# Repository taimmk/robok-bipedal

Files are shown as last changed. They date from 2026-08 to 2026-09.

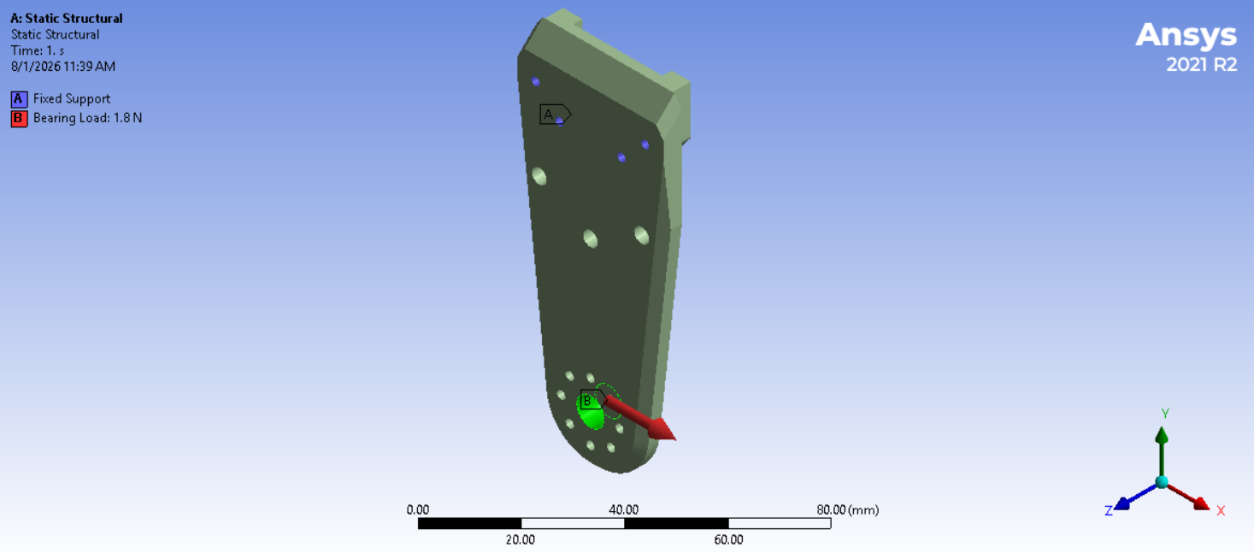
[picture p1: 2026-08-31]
docs/images/ANSYS/linki_setup.png

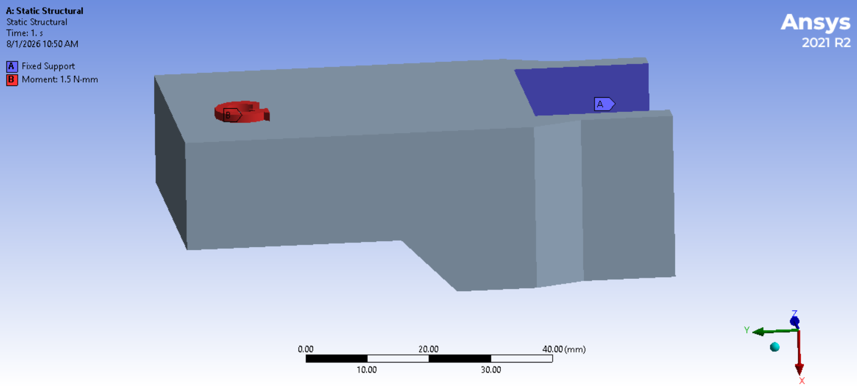
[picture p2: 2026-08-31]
docs/images/ANSYS/hiproll_setup.png

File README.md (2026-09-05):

# robok-bipedal

in this repo you will find all the resources I used to train the Robok (a custom bipedal designed by Taim MKAREM)
you will find all the info regarding installing the Isaac SIM 6.0.1 and training the robot from scratch in the docs/bipedal pdf file. 

for further information feel free to contact me on
taimmkarem@outlook.com

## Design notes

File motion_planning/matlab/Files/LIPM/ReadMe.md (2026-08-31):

# Motion Planning: LIPM Trajectory & Inverse Kinematics Pipeline

This directory contains the MATLAB workflow for generating balanced bipedal walking trajectories using the Linear Inverted Pendulum Model (LIPM), solving joint kinematics, and exporting trajectory matrices for Simulink.

---

## Workflow Overview

```text
[ applicationLIPM.mlapp ] ──> Tune & verify balance parameters
          │
          ▼
[ animateLIPM.m ] ──> Plot leg/COM trajectories ──> Generates: defaultfootinfos.mat
          │
          ▼
[ InverseKinematics_local.m ] ──> Calculate joint positions ──> Generates: IK trajectory data
          │
          ▼
[ Test_gen_mat.m ] ──> Format joint time-series ──> Generates: jointAngs_simulink_ready.mat
          │
          ▼
[ Simulink Model ] ──> Low-level robot execution
```

---

## Prerequisites

- **MATLAB** (R2023a or newer recommended)
- **Toolboxes:** Simulink, Simscape Multibody, Optimization Toolbox

---

## Step-by-Step Execution Guide

### 1. Balance Parameter Configuration

Launch the App Designer interface to configure and verify LIPM balance parameters:

```matlab
applicationLIPM
```

**Objective:** Adjust pendulum height ($z_0$), step time ($T_s$), and step length parameters to ensure zero-moment point (ZMP) stability for the physical robot specifications.

### 2. Trajectory Generation & Visualization

Apply the verified parameters to `animateLIPM.m` to generate and preview leg and Center of Mass (COM) trajectories:

```matlab
run('animateLIPM.m')
```

- **Output:** Displays animated robot walking gait and foot trajectory plots.
- **Generated Artifact:** `defaultfootinfos.mat` — stores target foot placements and time vectors.

### 3. Inverse Kinematics Computation

Compute the exact joint angles required to track the generated foot placements:

```matlab
run('InverseKinematics_local.m')
```

- **Input:** Automatically loads `defaultfootinfos.mat`.
- **Output:** Calculates leg joint positions across the stride cycle using the local-coordinate-frame IK solver.

### 4. Format Trajectories for Simulation

Convert raw joint trajectories into a time-series format optimized for Simulink import:

```matlab
run('Test_gen_mat.m')
```

- **Generated Artifact:** `jointAngs_simulink_ready.mat`

### 5. Load into Simulink

Move `jointAngs_simulink_ready.mat` to your main simulation workspace or load it before launching the Simulink environment:

```matlab
load('jointAngs_simulink_ready.mat');
```

---

## Data Artifacts Summary

| File Name | Producer Script | Description |
| --- | --- | --- |
| `defaultfootinfos.mat` | `animateLIPM.m` | Foot placement coordinates, step timing, and COM trajectories |
| `jointAngs_simulink_ready.mat` | `Test_gen_mat.m` | Time-series joint angle matrix formatted for Simulink block inputs |

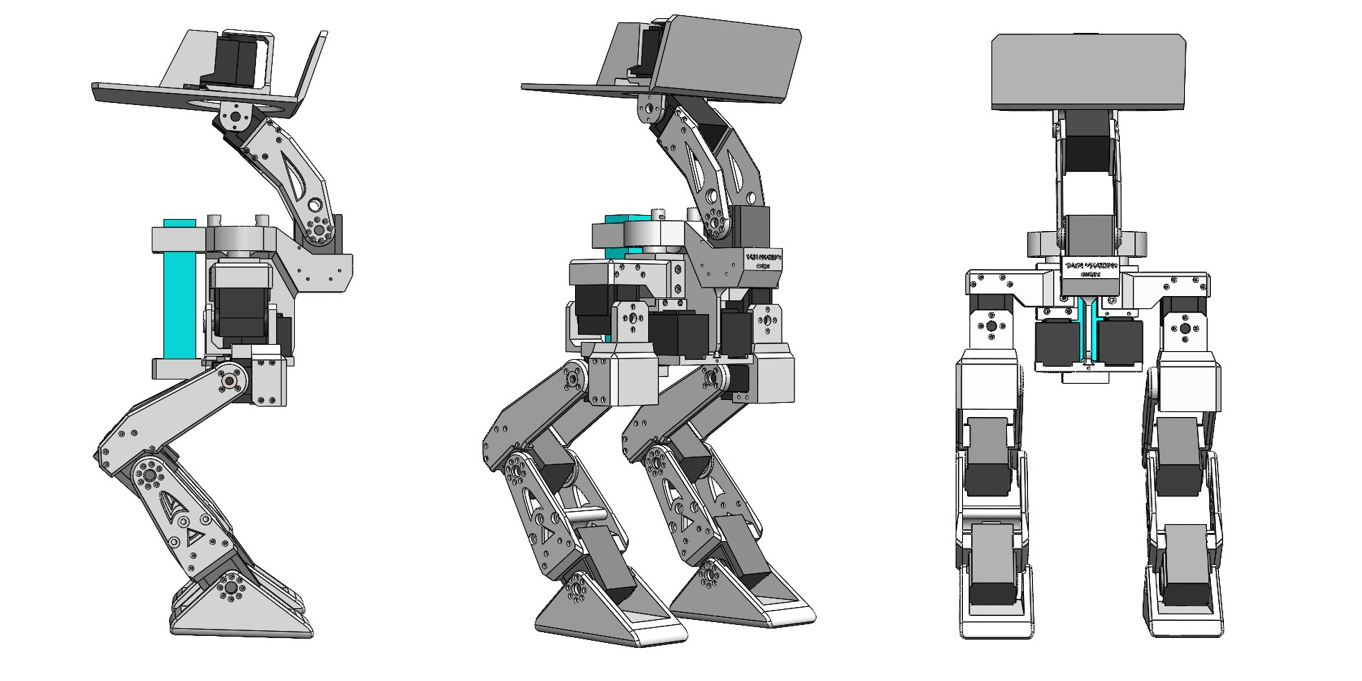
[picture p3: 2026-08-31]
docs/images/design1.png

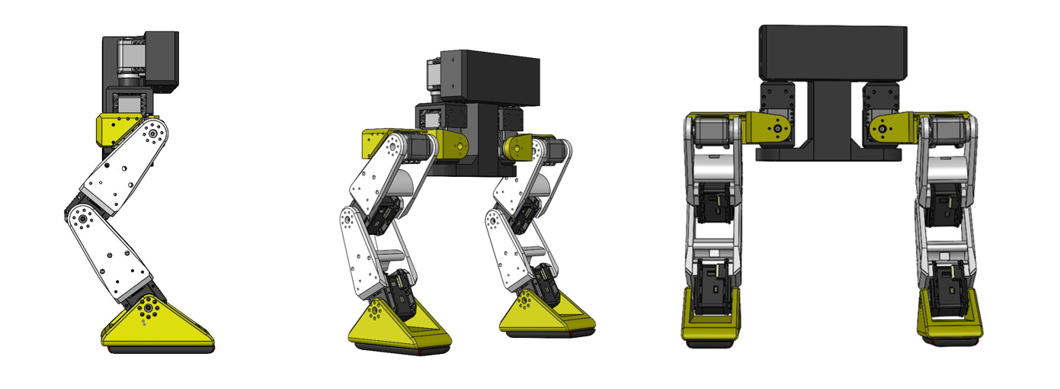
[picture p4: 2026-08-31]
docs/images/design0.png

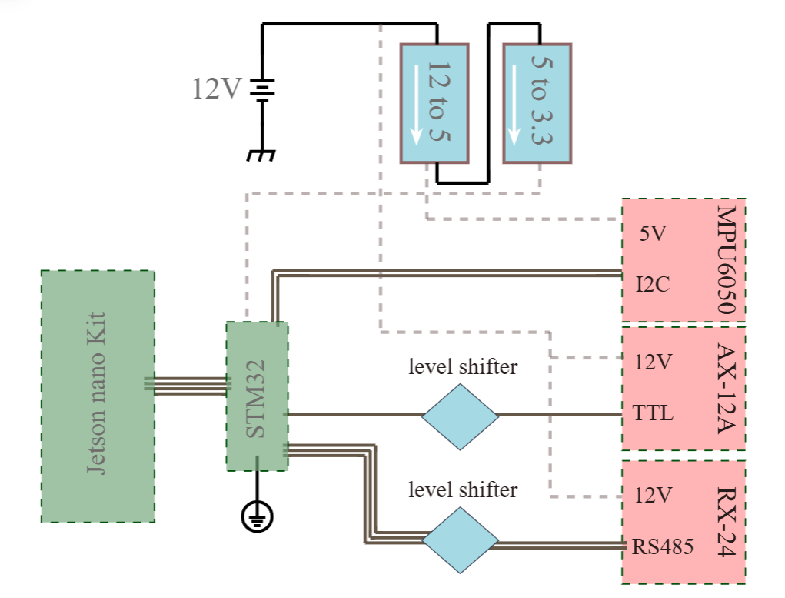
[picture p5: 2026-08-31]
docs/images/pcbdesign.png

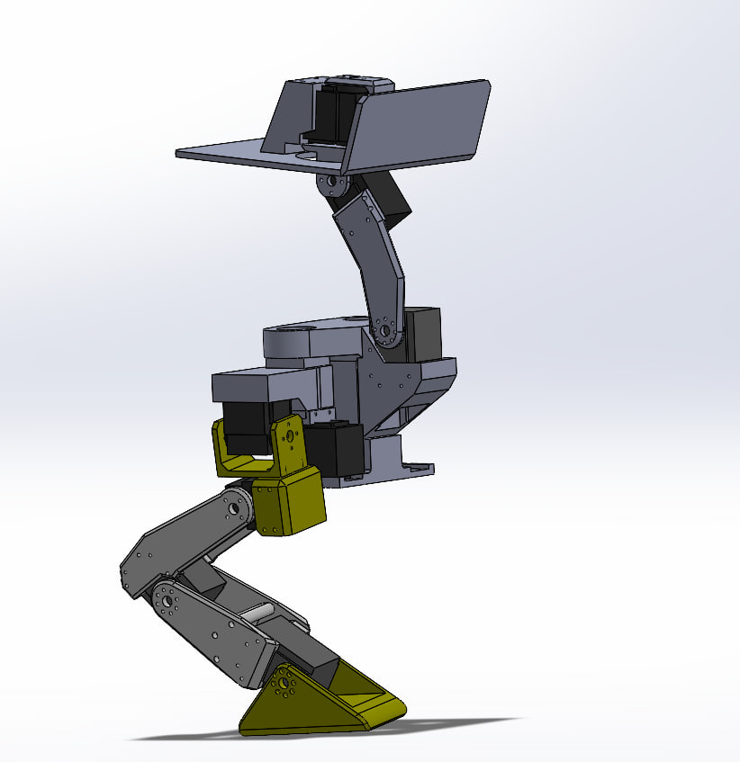
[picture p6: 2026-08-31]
docs/images/design01.jpg

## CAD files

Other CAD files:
mechanical/cad/robok_Assem.SLDASM
mechanical/cad/robok_Link.SLDPRT
mechanical/cad/robok_rollerbottom.SLDPRT
mechanical/cad/robok_body_bottom.SLDPRT
mechanical/cad/robok_LinkII_a.SLDPRT
mechanical/cad/robok_hiproll.SLDPRT
mechanical/cad/robok_hipIallined_lnew.SLDPRT
mechanical/cad/robok_hip_roll_train.SLDPRT
mechanical/cad/robok_nick_r.SLDPRT
mechanical/cad/robok_rx-28.SLDPRT
mechanical/cad/robok_hip_train.SLDPRT
mechanical/cad/robok_linkI_train.SLDPRT
mechanical/cad/robok_hipIallined_r.SLDPRT
mechanical/cad/robok_LinkII_train.SLDPRT
mechanical/cad/robok_nick_l.SLDPRT
mechanical/cad/robok_body.SLDPRT
mechanical/cad/robok_Link_pillar.SLDPRT
mechanical/cad/robok_roll_nick.SLDPRT
mechanical/cad/robok_LinkII_b.SLDPRT
mechanical/cad/robok_ax-12a.SLDPRT
mechanical/cad/robok_foot_r.SLDPRT
mechanical/cad/robok_foot_train.SLDPRT
mechanical/cad/robok_head.SLDPRT
mechanical/cad/robok_hipII.SLDPRT
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

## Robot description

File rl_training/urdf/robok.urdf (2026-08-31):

<?xml version="1.0" encoding="utf-8"?>
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
<robot name="robok">
  <link name="base_link">
    <inertial>
      <origin xyz="-0.0107845425844135 -0.142447918607034 -0.00419433105634964" rpy="0 0 0" />
      <mass value="0.28" />
      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
    </inertial>
    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
  </link>
  <link name="left_hipyaw">
    <inertial>
      <origin xyz="-0.0107845425844135 -0.142447918607034 -0.00419433105634965" rpy="0 0 0" />
      <mass value="0.28" />
      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
    </inertial>
    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
  </link>
  <joint name="hipyawl" type="revolute">
    <origin xyz="-0.0052029 0.026891 -0.019657" rpy="1.5708 0 -1.5695" />
    <parent link="base_link" />
    <child link="left_hipyaw" />
    <axis xyz="0 1 0" />
    <limit lower="-0.784" upper="0.784" effort="10" velocity="12" />
  </joint>
  <link name="left_hiproll">
    <inertial>
      <origin xyz="-0.0107845425844135 -0.142447918607034 -0.00419433105634964" rpy="0 0 0" />
      <mass value="0.28" />
      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
    </inertial>
    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
  </link>
  <joint name="hiprolll" type="revolute">
    <origin xyz="-0.048775 -0.063842 0" rpy="-3.1406 1.5708 3.1415" />
    <parent link="left_hipyaw" />
    <child link="left_hiproll" />
    <axis xyz="1 0 0" />
    <limit lower="-0.784" upper="0.784" effort="10" velocity="0.784" />
  </joint>
  <link name="left_hippitch">
    <inertial>
      <origin xyz="-0.0107845425844135 -0.142447918607034 -0.00419433105634964" rpy="0 0 0" />
      <mass value="0.28" />
      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
    </inertial>
    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
  </link>
  <joint name="hippitchl" type="revolute">
    <origin xyz="-0.0089572 -0.043273 0" rpy="0 0 -0.59366" />
    <parent link="left_hiproll" />
    <child link="left_hippitch" />
    <axis xyz="0 0 1" />
    <limit lower="-0.784" upper="0.784" effort="10" velocity="12" />
  </joint>
  <link name="left_anklepitch">
    <inertial>
      <origin xyz="-0.0107845425844135 -0.142447918607034 -0.00419433105634964" rpy="0 0 0" />
      <mass value="0.28" />
      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
    </inertial>
    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
  </link>
  <joint name="anklepitchl" type="revolute">
    <origin xyz="0.0046502 -0.087559 0" rpy="0 0 0.25743" />
    <parent link="left_hippitch" />
    <child link="left_anklepitch" />
    <axis xyz="0 0 1" />
    <limit lower="-0.784" upper="0.784" effort="10" velocity="12" />
  </joint>
  <link name="left_foot">
    <inertial>
      <origin xyz="-0.0107845425844135 -0.142447918607034 -0.00419433105634964" rpy="0 0 0" />
      <mass value="0.28" />
      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
    </inertial>
    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
  </link>
  <joint name="footl" type="revolute">
    <origin xyz="0.080808 -0.057712 0" rpy="0 0 0.34904" />
    <parent link="left_anklepitch" />
    <child link="left_foot" />
    <axis xyz="0 0 1" />
    <limit lower="-0.784" upper="0.784" effort="10" velocity="12" />
  </joint>
  <link name="right_hipyaw">
    <inertial>
      <origin xyz="-0.0107845425844135 -0.142447918607034 -0.00419433105634964" rpy="0 0 0" />
      <mass value="0.28" />
      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
    </inertial>
    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
  </link>
  <joint name="hipyawr" type="revolute">
    <origin xyz="-0.0048992 -0.018108 -0.019657" rpy="1.5708 0 1.5708" />
    <parent link="base_link" />
    <child link="right_hipyaw" />
    <axis xyz="0 1 0" />
    <limit lower="-0.784" upper="0.784" effort="10" velocity="12" />
  </joint>
  <link name="right_hiproll">
    <inertial>
      <origin xyz="-0.0107845425844135 -0.142447918607034 -0.00419433105634964" rpy="0 0 0" />
      <mass value="0.28" />
      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
    </inertial>
    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
  </link>
  <joint name="hiprollr" type="continuous">
    <origin xyz="-0.048775 -0.063842 0" rpy="0 -1.5708 0" />
    <parent link="right_hipyaw" />
    <child link="right_hiproll" />
    <axis xyz="1 0 0" />
    <limit lower="-0.784" upper="0.784" effort="10" velocity="12" />
  </joint>
  <link name="right_hippitch">
    <inertial>
      <origin xyz="-0.0107845425844135 -0.142447918607034 -0.00419433105634964" rpy="0 0 0" />
      <mass value="0.28" />
      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
    </inertial>
    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
  </link>
  <joint name="hippitchr" type="revolute">
    <origin xyz="-0.01048 -0.043273 0" rpy="0 0 -0.59125" />
    <parent link="right_hiproll" />
    <child link="right_hippitch" />
    <axis xyz="0 0 1" />
    <limit lower="-0.784" upper="0.784" effort="10" velocity="12" />
  </joint>
  <link name="right_anklepitch">
    <inertial>
      <origin xyz="-0.0107845425844135 -0.142447918607034 -0.00419433105634964" rpy="0 0 0" />
      <mass value="0.28" />
      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
    </inertial>
    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
  </link>
  <joint name="anklepitchr" type="revolute">
    <origin xyz="0.0046502 -0.087559 0" rpy="0 0 0.24642" />
    <parent link="right_hippitch" />
    <child link="right_anklepitch" />
    <axis xyz="0 0 1" />
    <limit lower="-0.784" upper="0.784" effort="10" velocity="12" />
  </joint>
  <link name="right_foot">
    <inertial>
      <origin xyz="-0.0107845425844135 -0.142447918607034 -0.00419433105634964" rpy="0 0 0" />
      <mass value="0.28" />
      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
    </inertial>
    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
  </link>
  <joint name="footr" type="revolute">
    <origin xyz="0.080808 -0.057712 0" rpy="0 0 0.35878" />
    <parent link="right_anklepitch" />
    <child link="right_foot" />
    <axis xyz="0 0 1" />
    <limit lower="-0.784" upper="0.784" effort="10" velocity="12" />
  </joint>
</robot>

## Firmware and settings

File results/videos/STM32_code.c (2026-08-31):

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
/* Includes ------------------------------------------------------------------*/
#include "main.h"
#include "adc.h"
#include "dma.h"
#include "i2c.h"
#include "spi.h"
#include "usart.h"
#include "usb_otg.h"
#include "gpio.h"

/* USER CODE BEGIN Includes */
#include <stdint.h>
#include <stdbool.h>
/* USER CODE END Includes */

/* USER CODE BEGIN PD */
// --- DYNAMIXEL PROTOCOL 1.0 MACROS ---
#define DXL_HEADER_1           0xFF
#define DXL_HEADER_2           0xFF
#define DXL_BROADCAST_ID       0xFE

#define DXL_INST_READ_DATA     0x02
#define DXL_INST_WRITE_DATA    0x03

#define DXL_REG_LED            0x19
#define DXL_REG_GOAL_POSITION  0x1E
#define DXL_REG_PRESENT_POS    0x24
/* USER CODE END PD */


/* USER CODE BEGIN PV */
// --- SYSTEM FLAGS ---
volatile bool imu_data_ready = false;

// --- NON-BLOCKING GLOBAL BUFFERS ---
uint8_t dxl_tx_buffer[64];      // Holds data safely while the background interrupt sends it
uint8_t dxl_usart1_echo[64];    // Catches the junk TTL echo in the background
/* USER CODE END PV */

void SystemClock_Config(void);
/* USER CODE BEGIN PFP */
// --- UNIFIED MULTI-BUS DYNAMIXEL FUNCTIONS ---
void Dynamixel_SendPacket(uint8_t* packet, uint16_t length);
uint8_t Calculate_Dxl_Checksum(uint8_t *packet, uint8_t total_packet_length);
void Dxl_WriteRegister(uint8_t id, uint8_t address, uint8_t *data, uint8_t data_length);
void Dynamixel_ChangeID(uint8_t current_id, uint8_t new_id);
void Dynamixel_SetPosition(uint8_t motor_id, uint16_t position);

bool Dxl_ReadRegister(UART_HandleTypeDef *huart, uint8_t id, uint8_t address, uint8_t bytes_to_read, uint8_t *out_data);

/* USER CODE END PFP */

/**
  * @brief  The application entry point.
  * @retval int
  */
int main(void)
{

  /* MCU Configuration--------------------------------------------------------*/

  /* Reset of all peripherals, Initializes the Flash interface and the Systick. */
  HAL_Init();

  /* Configure the system clock */
  SystemClock_Config();

  /* Initialize all configured peripherals */
  MX_GPIO_Init();
  MX_DMA_Init();
  MX_I2C2_Init();
  MX_USART1_UART_Init();
  MX_USART2_UART_Init();
  MX_SPI1_Init();
  MX_ADC1_Init();
  MX_USB_OTG_FS_USB_Init();
  /* USER CODE BEGIN 2 */
  HAL_GPIO_WritePin(GPIOA, GPIO_PIN_9, GPIO_PIN_RESET);
	uint8_t led_on = 1;
	uint8_t led_off = 0;
  /* USER CODE END 2 */

  /* Infinite loop */
  /* USER CODE BEGIN WHILE */
  while (1)
  {
    /* USER CODE END WHILE */

    /* USER CODE BEGIN 3 */
	  // -----------------------------------------------------------------
	  // 1. IMU INTERRUPT PROCESSING TASK
	  // -----------------------------------------------------------------
	  if (imu_data_ready == true)
	  {
		  imu_data_ready = false; // Acknowledge and clear the flag

	  }

	  // -----------------------------------------------------------------
	  // 2. DYNAMIXEL PILOT CONTROL ROUTINE
	  // -----------------------------------------------------------------
	  // Alternate state commands across both separate physical networks

	  // Turn LEDs ON for Motor ID 1 (TTL Bus) and Motor ID 2 (RS485 Bus)
	  	  uint8_t id = 2;
		  // Example A: Change a motor from broadcast (any ID) to ID 2
		  //Dynamixel_ChangeID(0xFE, id);


	  	  Dxl_WriteRegister(id, DXL_REG_LED, &led_on, 1);
		  HAL_Delay(250);
		  // 1. HEARTBEAT: Toggle the onboard LED (PC13)
			HAL_GPIO_TogglePin(GPIOC, GPIO_PIN_13);
		  // Turn LEDs OFF
		  Dxl_WriteRegister(id, DXL_REG_LED, &led_off, 1);
		  HAL_Delay(250);

		  Dynamixel_SetPosition(id, 512);
  }
  /* USER CODE END 3 */
}

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
/* USER CODE BEGIN 4 */
// ==============================================================================
// READ REGISTER FUNCTION (PROTOCOL 1.0)
// ==============================================================================
bool Dxl_ReadRegister(UART_HandleTypeDef *huart, uint8_t id, uint8_t address, uint8_t bytes_to_read, uint8_t *out_data)
{
    // 1. Construct the Read Instruction Packet
    uint8_t tx_packet[8];
    tx_packet[0] = 0xFF;          // Header 1
    tx_packet[1] = 0xFF;          // Header 2
    tx_packet[2] = id;            // Target ID
    tx_packet[3] = 0x04;          // Length: Always 4 for a READ instruction
    tx_packet[4] = 0x02;          // Instruction: READ_DATA (0x02)
    tx_packet[5] = address;       // Starting Memory Address
    tx_packet[6] = bytes_to_read; // How many bytes to read

    uint32_t checksum_sum = tx_packet[2] + tx_packet[3] + tx_packet[4] + tx_packet[5] + tx_packet[6];
    tx_packet[7] = (uint8_t)(~checksum_sum); // Bitwise NOT of the lowest byte

    // 2. Clear any lingering junk in the UART hardware RX buffer before transmitting
    __HAL_UART_FLUSH_DRREGISTER(huart);

    // 3. Transmit the Request based on the Bus Type
    if (huart->Instance == USART2)
    {
        // RS485 Bus: Assert Transmit Mode
        HAL_GPIO_WritePin(GPIOA, GPIO_PIN_9, GPIO_PIN_SET);
        HAL_UART_Transmit(huart, tx_packet, 8, 10);

        // Wait for shift register to empty
        while (__HAL_UART_GET_FLAG(huart, UART_FLAG_TC) == RESET) {}

        // CRITICAL: Drop PA9 to listen mode IMMEDIATELY. Do not put a HAL_Delay() here!
        HAL_GPIO_WritePin(GPIOA, GPIO_PIN_9, GPIO_PIN_RESET);
    }
    else if (huart->Instance == USART1)
    {
        // TTL Bus
        uint8_t dummy_echo[8];
        HAL_UART_Transmit(huart, tx_packet, 8, 10);

        // Drain the local echo of our own TX packet before listening for the real response
        HAL_UART_Receive(huart, dummy_echo, 8, 5);
    }

    // 4. Receive the Motor's Reply
    // Expected RX size: 6 framing bytes (Header, Header, ID, Length, Error, Checksum) + Payload
    uint8_t expected_rx_len = 6 + bytes_to_read;
    uint8_t rx_buffer[16] = {0}; // Generous buffer size for most reads

    // Listen with a strict 5ms timeout. If the motor is unplugged, the code won't freeze here.
    if (HAL_UART_Receive(huart, rx_buffer, expected_rx_len, 5) == HAL_OK)
    {
        // Validate the packet header and ID
        if (rx_buffer[0] == 0xFF && rx_buffer[1] == 0xFF && rx_buffer[2] == id)
        {
            // Extract the requested data (starts at index 5 in the status packet)
            for (uint8_t i = 0; i < bytes_to_read; i++)
            {
                out_data[i] = rx_buffer[5 + i];
            }
            return true; // Success!
        }
    }

    return false; // Read failed, timeout, or bad packet
}
void Dynamixel_SetPosition(uint8_t motor_id, uint16_t position)
{
    // Restrict the position parameter to the maximum allowed limit
    if (position > 1023) {
        position = 1023;
    }

    // Split the 16-bit position into two 8-bit registers (Low Byte and High Byte)
    uint8_t pos_low  = (uint8_t)(position & 0xFF);
    uint8_t pos_high = (uint8_t)((position >> 8) & 0xFF);

    // A standard 2-byte write packet has exactly 9 bytes
    uint8_t packet[9];

    packet[0] = 0xFF;         // Header 1
    packet[1] = 0xFF;         // Header 2
    packet[2] = motor_id;     // Target Motor ID
    packet[3] = 0x05;         // Length: 3 + number of parameters (Address + 2 Data Bytes)
    packet[4] = 0x03;         // Instruction: WRITE
    packet[5] = 0x1E;         // Control Table Start Address: 0x1E (Goal Position Reg)
    packet[6] = pos_low;      // Parameter 1: Goal Position Low Byte
    packet[7] = pos_high;     // Parameter 2: Goal Position High Byte

    // Calculate Checksum: ~ (ID + Length + Instruction + Address + Param1 + Param2)
    uint32_t checksum_sum = packet[2] + packet[3] + packet[4] + packet[5] + packet[6] + packet[7];
    packet[8] = (uint8_t)(~checksum_sum); // Bitwise NOT of the lowest byte

    Dynamixel_SendPacket(packet, sizeof(packet));

}
void Dynamixel_ChangeID(uint8_t current_id, uint8_t new_id)
{
    // A Dynamixel WRITE packet to the ID register has exactly 8 bytes
    uint8_t packet[8];

    packet[0] = 0xFF;         // Header 1
    packet[1] = 0xFF;         // Header 2
    packet[2] = current_id;   // Target ID (or 0xFE Broadcast)
    packet[3] = 0x04;         // Length: 3 + number of parameters (Address + Value)
    packet[4] = 0x03;         // Instruction: WRITE
    packet[5] = 0x03;         // Control Table Address: 0x03 is the ID register
    packet[6] = new_id;       // Parameter: The new ID value

    // Calculate the Checksum: ~ (ID + Length + Instruction + Address + Value)
    uint32_t checksum_sum = packet[2] + packet[3] + packet[4] + packet[5] + packet[6];
    packet[7] = (uint8_t)(~checksum_sum); // Take the bitwise NOT of the lowest byte


    // 2. Transmit the packet over your UART instance
    Dynamixel_SendPacket(packet, sizeof(packet));
}
// ==============================================================================
// HARDWARE INTERRUPT ROUTINE (EXTI)
// ==============================================================================
void HAL_GPIO_EXTI_Callback(uint16_t GPIO_Pin)
{
    // Capture transitions on PC14 or PC15 (IMU Hardware Interrupt Output Lines)
    if(GPIO_Pin == GPIO_PIN_14 || GPIO_Pin == GPIO_PIN_15)
    {
        imu_data_ready = true; // Signal main thread context to handle communication
    }
}


// ==============================================================================
// DYNAMIXEL PACKET FORMATTING LAYER (PROTOCOL 1.0)
// ==============================================================================
uint8_t Calculate_Dxl_Checksum(uint8_t *packet, uint8_t total_packet_length)
{
    uint32_t sum = 0;
    for(uint8_t i = 2; i < (total_packet_length - 1); i++)
    {
        sum += packet[i];
    }
    return (uint8_t)(~sum & 0xFF);
}

void Dxl_WriteRegister( uint8_t id, uint8_t address, uint8_t *data, uint8_t data_length)
{
    uint8_t tx_buffer[32];
    uint8_t total_packet_size = data_length + 7;

    tx_buffer[0] = DXL_HEADER_1;
    tx_buffer[1] = DXL_HEADER_2;
    tx_buffer[2] = id;
    tx_buffer[3] = data_length + 3; // Length parameter field
    tx_buffer[4] = DXL_INST_WRITE_DATA;
    tx_buffer[5] = address;

    for(uint8_t i = 0; i < data_length; i++)
    {
        tx_buffer[6 + i] = data[i];
    }

    tx_buffer[total_packet_size - 1] = Calculate_Dxl_Checksum(tx_buffer, total_packet_size);

    Dynamixel_SendPacket(tx_buffer, total_packet_size);
}
// ==============================================================================
// BROADCAST TO ALL BUSES
// ==============================================================================
void Dynamixel_SendPacket(uint8_t* packet, uint16_t length)
{
    // --- 1. SEND TO RS485 BUS (USART2) ---
    // Assert Driver Enable High to put MAX485 in transmit mode
    HAL_GPIO_WritePin(GPIOA, GPIO_PIN_9, GPIO_PIN_SET);

    // Send the data
    HAL_UART_Transmit(&huart2, packet, length, 100);

    // Wait for the hardware shift register to empty completely
    while (__HAL_UART_GET_FLAG(&huart2, UART_FLAG_TC) == RESET) {}
    HAL_Delay(1); // Brief timing stabilization cushion

    // Assert Driver Enable Low to return MAX485 to listening mode
    HAL_GPIO_WritePin(GPIOA, GPIO_PIN_9, GPIO_PIN_RESET);


    // --- 2. SEND TO TTL BUS (USART1) ---
    uint8_t echoBuffer[255];

    // Send the data natively
    if (HAL_UART_Transmit(&huart1, packet, length, 100) == HAL_OK)
    {
        // Drain the physical local loopback echo immediately from the RX buffer
        HAL_UART_Receive(&huart1, echoBuffer, length, 10);
    }
}

/* USER CODE END 4 */
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
